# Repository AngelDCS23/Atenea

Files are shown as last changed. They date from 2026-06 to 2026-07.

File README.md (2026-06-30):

# Atenea — Cohete de 2 etapas con aviónica avanzada

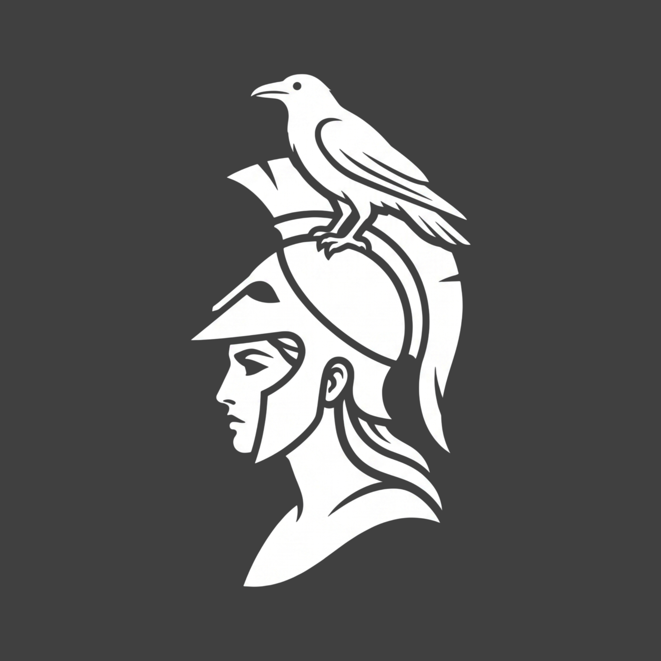
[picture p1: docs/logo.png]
Logo del proyecto


Atenea es un proyecto de cohete casero de dos etapas orientado al desarrollo de una aviónica robusta, modular y experimental. El objetivo es integrar sensores, control de vuelo, telemetría y seguimiento de antena para conseguir un sistema capaz de monitorizar y gestionar el vuelo de forma segura.

El proyecto está organizado en distintas áreas de trabajo:

- firmware: software embebido para la electrónica de vuelo y la estación terrestre.
- hardware: diseño y construcción de estructuras, electrónica y componentes mecánicos.
- ground_station: herramientas para recepción y procesamiento de datos.
- docs: documentación técnica y referencias del proyecto.

## Características principales

- Cohete de dos etapas con lógica de vuelo supervisada.
- Aviónica basada en ESP32-S3 para adquisición de datos y control.
- Integración de sensores como giroscopio, acelerómetro y barómetro.
- Máquina de estados para gestionar fases como despegue, separación, apogeo y recuperación.
- Telemetría por radio para seguimiento en tiempo real.
- Sistema de rastreo de antena para mejorar la recepción durante el vuelo.
- Enfoque modular para facilitar pruebas, desarrollo y futuras mejoras.

## Arquitectura general

El sistema se organiza en varios subsistemas clave:

1. Sensado y control
   - Lectura continua de sensores de actitud y presión.
   - Procesado en tiempo real para estimar el comportamiento del vehículo.
   - Implementación de estrategias de estabilidad activa.

2. Máquina de estados de vuelo
   - Gestión de eventos críticos del vuelo.
   - Transiciones seguras entre distintas fases.
   - Supervisión para prevenir acciones no deseadas.

3. Telemetría y comunicación
   - Transmisión de datos desde el cohete hacia la estación en tierra.
   - Uso de módulos de radio de bajo coste y alta simplicidad para enlaces de corto y medio alcance.

4. Seguimiento de antena
   - Posicionamiento automático de una antena direccional para mantener la comunicación.
   - Integración con datos de localización del cohete.

## Estructura del repositorio

- [docs](docs): documentación técnica general del proyecto.
- [firmware](firmware): código fuente para la aviónica del cohete y la estación.
- [ground_station](ground_station): aplicaciones o scripts para la estación terrestre.
- [hardware](hardware): diseños, modelos 3D y esquemas.

## Documentación relacionada

La documentación técnica más completa se encuentra en [docs/Proyecto_Cohete_Avionica.md](docs/Proyecto_Cohete_Avionica.md).

## Estado del desarrollo

El proyecto se encuentra en una fase inicial de desarrollo, centrada en la definición de la arquitectura, la selección de sensores y la implementación de los primeros módulos de firmware y hardware.

## Próximos pasos

- Definir y validar la lógica de la máquina de estados.
- Implementar la lectura y fusión de sensores para estimación de actitud.
- Integrar telemetría con la estación terrestre.
- Probar los subsistemas de control y recuperación.
- Continuar el desarrollo del hardware y la estructura del cohete.

## Licencia

Este proyecto se encuentra en desarrollo y su uso está orientado a fines educativos y experimentales.

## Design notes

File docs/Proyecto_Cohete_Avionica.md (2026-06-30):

# Proyecto Cohete Casero de 2 Etapas con Aviónica Avanzada (ESP32-S3)

Este documento recopila la estructura técnica, desafíos, soluciones y presupuesto estimado para el desarrollo de un cohete casero de dos etapas controlado por un **ESP32-S3 Sense**, incluyendo sistemas de estabilidad activa, telemetría y un rastreador de antena automatizado (*Antenna Tracker*).

---

## 1. Arquitectura del Sistema de Aviónica

Para ejecutar cálculos en tiempo real (como la estimación de actitud mediante fusión de sensores), el código del ESP32-S3 se estructurará en dos tareas principales aprovechando sus dos núcleos a 240 MHz:

* **Núcleo 0 (Control de Vuelo y Telemetría):** Lectura de la IMU (giroscopio/acelerómetro) y barómetro a alta frecuencia (100Hz - 200Hz), ejecución del algoritmo PID para los alerones activos y almacenamiento de datos en la tarjeta SD.
* **Núcleo 1 (Máquina de Estados de Vuelo y Cámara):** Gestión de la seguridad, detección de eventos de la Máquina de Estados (despegue, separación, apogeo), activación de servomotores de eyección y captura de imágenes/video.

### Máquina de Estados de Vuelo (FSM)
El software debe actuar como una máquina de estados finitos ultra-robusta sin el uso de funciones bloqueantes (`delay()`):
1.  **REPOSO (Pre-lanzamiento):** Calibración de sensores y espera de umbral de aceleración.
2.  **QUEMADO ETAPA 1:** Detección de aceleración positiva continua (> 2g).
3.  **SEPARACIÓN:** Caída drástica de la aceleración axial que indica el fin del empuje de la primera etapa.
4.  **ENCENDIDO ETAPA 2 (Condicionado):** *Regla de Oro de Seguridad:* Solo se activa si el ángulo de inclinación respecto a la vertical es inferior a 15°. Si es mayor, se aborta el encendido.
5.  **APOGEO:** Detección de velocidad vertical igual a cero y tendencia de presión barométrica negativa. Activación del paracaídas.
6.  **RECUPERACIÓN:** Transmisión de coordenadas GPS de alta prioridad hasta el aterrizaje.

---

## 2. Subsistemas Clave y Soluciones Técnicas

### Estabilidad Activa mediante Alerones (Opción Seleccionada)
* **Mecanismo:** 4 aletas aerodinámicas en la parte superior (*canards*) movidas por servomotores para corregir desviaciones en pleno vuelo.
* **Hardware:** Servos digitales **MG90S** con piñonería metálica, alimentados a 6V o 7.4V para maximizar la velocidad de respuesta (~0.08s por 60°). Al requerir deflexiones pequeñas (±5° a ±10°), el tiempo de reacción físico se reduce a unos ~6 milisegundos.
* **Software:** Algoritmo PID nativo utilizando el periférico MCPWM del ESP32 configurado a 200Hz o más, evitando ruidos de la IMU mediante filtros paso bajo (Low-Pass Filter).

### Propulsión y Combustible
* Se descartan los motores comerciales costosos y la cocción inestable de azúcar al fuego en interiores (riesgo crítico de CATO/explosión y autoignición).
* **Solución económica:** Uso de **Cohetes de Agua** (liberación mecánica mediante servos, coste 0€ por lanzamiento) o **Azúcar prensado en seco** (sin cocinar, requiriendo pruebas estáticas previas en un banco de tierra sin la electrónica a bordo).

### Telemetría y Enlace de Radio
* Se descarta el uso de tecnologías móviles (5G/4G) por el elevado coste de los módulos (100€-250€), las zonas muertas en altitud y el Efecto Doppler a alta velocidad.
* **Solución:** Módulos de radiofrecuencia de bajo coste como **LoRa (SX1278 a 868/915 MHz)** o transceptores **HC-12 (433 MHz)** conectados vía UART, permitiendo un alcance de entre 800m y 3km con antenas de látigo flexibles orientadas hacia abajo.

### Rastreador de Antena Automático (*Antenna Tracker*)
* **Funcionamiento:** Una estructura móvil *Pan-Tilt* en tierra equipada con una antena direccional de alta ganancia (tipo Yagi casera) que apunta automáticamente hacia el cohete.
* **Lógica:** El cohete envía sus coordenadas GPS (módulo **NEO-6M**). Un script de Python en el portátil (o un microcontrolador secundario en tierra) realiza el cálculo de trigonometría esférica (Azimut y Elevación) comparándolo con la posición de la estación base y mueve dos servos de alta potencia (**MG996R**).

---

## 3. Desglose del Presupuesto Estimado

A continuación se detalla la tabla de precios calculada para el enfoque de desarrollo "Low-Cost", asumiendo que ya se dispone del portátil y del procesador principal (**ESP32-S3 Sense**).

| Componente / Subsistema | Descripción / Función técnica | Cantidad | Precio Unitario (€) | Precio Total Estimado (€) |
| :--- | :--- | :---: | :---: | :---: |
| **Módulo GPS NEO-6M** | Localización del cohete y guiado del rastreador | 1 | 5,00 € | 5,00 € |
| **Transmisores de Radio** | Enlace inalámbrico (Módulos LoRa o HC-12) para cohete y tierra | 2 | 5,00 € | 10,00 € |
| **Servos Digitales MG90S** | Servomotores rápidos con piñones de metal para los alerones activos | 2 | 4,00 € | 8,00 € |
| **Micro Servo SG90** | Servomotor básico para el pestillo de eyección del paracaídas | 1 | 2,00 € | 2,00 € |
| **Batería LiPo 2S (7.4V)** | Alimentación dedicada para servos y aviónica del cohete (ej. 450mAh) | 1 | 7,00 € | 7,00 € |
| **Adaptador USB a TTL** | Chip CP2102 para conectar el receptor de radio de tierra al portátil | 1 | 2,00 € | 2,00 € |
| **Microcontrolador Tierra** | Placa Arduino Nano (clon) para controlar los servos del rastreador | 1 | 3,00 € | 3,00 € |
| **Servos de Potencia MG996R** | Servomotores de alto torque para el movimiento Pan-Tilt de la antena | 2 | 5,00 € | 10,00 € |
| **Antena Yagi Casera** | Fabricación propia con varillas de metal/perchas y conectores | 1 | 2,00 € | 2,00 € |
| **Fuselaje y Estructura** | Tubos de cartón/PVC, botellas PET, tornillería y filamento 3D | - | 10,00 € | 10,00 € |
| **Material Paracaídas** | Tela ligera de paraguas viejo o bolsa resistente e hilo de pescar | 1 | 2,00 € | 2,00 € |
| **TOTAL ESTIMADO** | **Coste de hardware para el sistema aeroespacial completo** | - | - | **61,00 €** |

*Nota sobre la propulsión:* Si se opta por cohetes de agua, el coste operativo es de 0,00€. En caso de utilizar propulsor de azúcar (KNO3 + Azúcar glass), los ingredientes químicos añaden aproximadamente **10,00 €** adicionales para múltiples lotes de prueba.

---

## 4. Próximos Pasos con el Giroscopio de 6 Ejes

Dado que vas a comenzar por el sistema de medición de actitud, ten en cuenta estas tres pautas clave para tu IMU de 6 ejes:

1.  **Configuración de Rango Máximo:** Configura el giroscopio a su escala completa (típicamente **±2000 °/s**) y el acelerómetro a **±16g**. Los valores por defecto de desarrollo (como ±2g) se saturarán instantáneamente con la vibración y aceleración del despegue.
2.  **Amortiguación Mecánica:** No atornilles ni pegues la IMU directamente a la estructura rígida del cohete. El ruido de alta frecuencia del motor falseará las lecturas. Usa espuma de alta densidad o gel de silicona entre el chasis y la PCB.
3.  **Algoritmo de Fusión:** Implementa un filtro complementario (ligero y rápido) o un filtro de Kalman optimizado en el Núcleo 0 para combinar las lecturas del giroscopio (preciso a corto plazo) con el acelerómetro (estable a largo plazo) y obtener el ángulo real de inclinación en tiempo real.

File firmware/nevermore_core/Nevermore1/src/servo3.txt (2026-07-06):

#include <Arduino.h>
#include "I2Cdev.h"
#include "MPU6050.h"
#include "Wire.h"
#include <ESP32Servo.h> 

MPU6050 sensor;

Servo servoPitch1;
Servo servoPitch2;
const int PIN_SERVO_PITCH1 = 1;
const int PIN_SERVO_PITCH2 = 2; 

Servo servoRoll;
const int PIN_SERVO_ROLL = 3; 

int16_t ax, ay, az;
int16_t gx, gy, gz;

float pitch = 0.0;
float roll = 0.0;
unsigned long tiempoAnterior;

const float SETPOINT = 0.0; 
const int CENTRO_SERVO = 90;

float Kp = 1.0;  
float Ki = 0.0;  
float Kd = 0.05; 

float errorPrevioPitch = 0.0;
float errorIntegralPitch = 0.0;

float errorPrevioRoll = 0.0;
float errorIntegralRoll = 0.0;

void setup() {
  Serial.begin(115200);
  Wire.begin(5, 6); 
  
  sensor.initialize();

  sensor.setFullScaleGyroRange(MPU6050_GYRO_FS_2000);
  sensor.setFullScaleAccelRange(MPU6050_ACCEL_FS_8);

  if (sensor.testConnection()) {
      Serial.println("Sensor MPU6050 iniciado correctamente con GPIO 5 y 6");
  } else {
      Serial.println("Error al iniciar el sensor MPU6050");
  }

  servoPitch1.attach(PIN_SERVO_PITCH1, 500, 2500); 
  servoPitch2.attach(PIN_SERVO_PITCH2, 500, 2500); 
  servoPitch1.write(CENTRO_SERVO);
  servoPitch2.write(CENTRO_SERVO);

  servoRoll.attach(PIN_SERVO_ROLL, 500, 2500);
  servoRoll.write(CENTRO_SERVO);

  tiempoAnterior = micros();
}

void loop() {
  // 1. LEER SENSOR
  sensor.getAcceleration(&ax, &ay, &az);
  sensor.getRotation(&gx, &gy, &gz);

  unsigned long tiempoActual = micros();
  float dt = (tiempoActual - tiempoAnterior) / 1000000.0;
  tiempoAnterior = tiempoActual;

  float accelRoll = atan2(ay, az) * 180.0 / M_PI;
  float accelPitch = atan2(-ax, sqrt((float)ay * (float)ay + (float)az * (float)az)) * 180.0 / M_PI;

  float gyroX_dps = gx / 16.4;
  float gyroY_dps = gy / 16.4;

  roll = 0.95 * (roll + gyroX_dps * dt) + 0.05 * accelRoll;
  pitch = 0.95 * (pitch + gyroY_dps * dt) + 0.05 * accelPitch;

  float errorPitch = SETPOINT - pitch;
  
  errorIntegralPitch += (errorPitch * dt);
  errorIntegralPitch = constrain(errorIntegralPitch, -20.0, 20.0); 

  float derivativoPitch = (errorPitch - errorPrevioPitch) / dt;
  float salidaPID_Pitch = (Kp * errorPitch) + (Ki * errorIntegralPitch) + (Kd * derivativoPitch);
  errorPrevioPitch = errorPitch;

  if (abs(salidaPID_Pitch) < 1.0) salidaPID_Pitch = 0.0;

  int anguloPitch = CENTRO_SERVO - salidaPID_Pitch;
  anguloPitch = constrain(anguloPitch, 60, 120);

  servoPitch1.write(anguloPitch);
  servoPitch2.write(anguloPitch); 

  float errorRoll = SETPOINT - roll;
  
  errorIntegralRoll += (errorRoll * dt);
  errorIntegralRoll = constrain(errorIntegralRoll, -20.0, 20.0);

  float derivativoRoll = (errorRoll - errorPrevioRoll) / dt;
  float salidaPID_Roll = (Kp * errorRoll) + (Ki * errorIntegralRoll) + (Kd * derivativoRoll);
  errorPrevioRoll = errorRoll;

  if (abs(salidaPID_Roll) < 1.0) salidaPID_Roll = 0.0;

  int anguloRoll = CENTRO_SERVO + salidaPID_Roll; 
  anguloRoll = constrain(anguloRoll, 60, 120);

  servoRoll.write(anguloRoll);

  Serial.print("Pitch:"); Serial.print(pitch); Serial.print(",");
  Serial.print("Roll:");  Serial.print(roll);  Serial.print(",");
  Serial.print("Angulo_Pitch:"); Serial.print(anguloPitch); Serial.print(",");
  Serial.print("Angulo_Roll:");  Serial.println(anguloRoll);

  delay(10); 
}

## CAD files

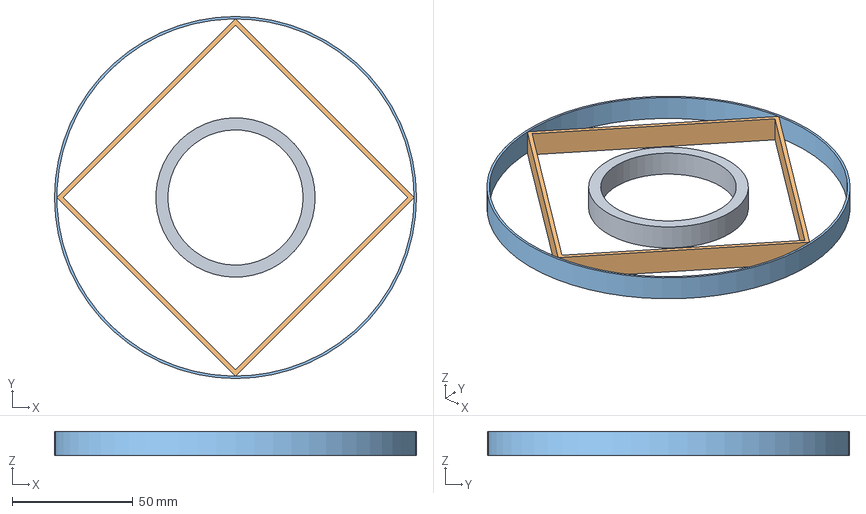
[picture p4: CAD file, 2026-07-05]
hardware/prototipo1.FCStd
150.0 x 150.0 x 10.0 mm

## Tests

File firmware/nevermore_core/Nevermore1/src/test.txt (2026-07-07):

#include <Arduino.h>
#include <ESP32Servo.h>

Servo miServoMetal;
Servo miServoMetal2;
Servo miServoPlastic;

// Usamos el pin físico D1 (que equivale al GPIO2), 
// ya que comprobaste que funciona perfectamente.
const int PIN_SERVOP = 1;
const int PIN_SERVO = 2; 
const int PIN_SERVO2 = 3;

void setup() {
  Serial.begin(115200);
  
  // Espera activa para que no te pierdas los textos por el USB
  while (!Serial) {
    delay(10);
  }
  
  Serial.println("--- TEST DE FUERZA PARA SERVO MG90S ---");
  
  // Configuramos el servo con los anchos de pulso estándar
  miServoPlastic.attach(PIN_SERVOP, 500, 2500);
  miServoMetal.attach(PIN_SERVO, 500, 2500);
  miServoMetal2.attach(PIN_SERVO2, 500, 2500);
}

void loop() {
  Serial.println("Posicion: 0 grados");
  miServoPlastic.write(0);
  miServoMetal.write(0);
  miServoMetal2.write(0);
  delay(1500); // Tiempo suficiente para que el motor llegue y exija corriente

  Serial.println("Posicion: 90 grados (Centro)");
  miServoPlastic.write(90);
  miServoMetal.write(90);
  miServoMetal2.write(90);
  delay(1500);

  Serial.println("Posicion: 180 grados");
  miServoPlastic.write(180);
  miServoMetal.write(180);
  miServoMetal2.write(180);
  delay(1500);
  
  Serial.println("Volviendo a: 90 grados (Centro)");
  miServoPlastic.write(90);
  miServoMetal.write(90);
  miServoMetal2.write(90);
  delay(1500);
  
  Serial.println("---------------------------------------");
}

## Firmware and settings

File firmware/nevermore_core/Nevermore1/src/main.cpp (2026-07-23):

#include <Arduino.h>
#include "I2Cdev.h"
#include "MPU6050.h"
#include "Wire.h"
#include <ESP32Servo.h> 
#include <TinyGPSPlus.h>

#define GPS_RX_PIN 44
#define GPS_TX_PIN 43

MPU6050 sensor;
TinyGPSPlus gps;

unsigned long ultimoAviso = 0;

// --- CONFIGURACIÓN DE LOS SERVOS ---
Servo servo_EjeX;     // El que se moverá con la inclinación X
Servo servo_EjeY_1;   // El que se moverá con la inclinación Y (Motor 1)
Servo servo_EjeY_2;   // El que se moverá con la inclinación Y (Motor 2)

const int PIN_SERVO_X = D0; 
const int PIN_SERVO_Y1 = D1;
const int PIN_SERVO_Y2 = D2;

int16_t ax, ay, az;
int16_t gx, gy, gz;

float pitch = 0.0; // Lo usaremos como Eje X
float roll = 0.0;  // Lo usaremos como Eje Y

unsigned long tiempoAnterior;

const float SETPOINT_X = 0.0; 
const float SETPOINT_Y = 0.0;
const int CENTRO_SERVO = 90;

// Constantes PID Eje X
float KpX = 1.0;
float KiX = 0.0;
float KdX = 0.05;

// Constantes PID Eje Y
float KpY = 0.8;
float KiY = 0.0;
float KdY = 0.05;

// Memoria del PID
float errorPrevioX = 0.0;
float errorIntegralX = 0.0;
float errorPrevioY = 0.0;
float errorIntegralY = 0.0;

void setup() {
  Serial.begin(115200);
  Wire.begin();
  sensor.initialize();

  Serial1.begin(9600, SERIAL_8N1, GPS_RX_PIN, GPS_TX_PIN);
  sensor.setFullScaleGyroRange(MPU6050_GYRO_FS_2000);
  sensor.setFullScaleAccelRange(MPU6050_ACCEL_FS_8);

  if (sensor.testConnection()) {
      Serial.println("Sensor iniciado correctamente");
  } else {
      Serial.println("Error al iniciar el sensor");
  }

  // 1. Asignar temporizadores independientes
  ESP32PWM::allocateTimer(0);
  ESP32PWM::allocateTimer(1);
  ESP32PWM::allocateTimer(2);
  ESP32PWM::allocateTimer(3);

  // 2. Definir la frecuencia
  servo_EjeX.setPeriodHertz(50);
  servo_EjeY_1.setPeriodHertz(50);
  servo_EjeY_2.setPeriodHertz(50);

  // 3. Conectar a los pines
  servo_EjeX.attach(PIN_SERVO_X, 500, 2500);
  servo_EjeY_1.attach(PIN_SERVO_Y1, 500, 2500);
  servo_EjeY_2.attach(PIN_SERVO_Y2, 500, 2500);
  
  // 4. Centrar los motores
  servo_EjeX.write(CENTRO_SERVO);
  servo_EjeY_1.write(CENTRO_SERVO);
  servo_EjeY_2.write(CENTRO_SERVO);

  tiempoAnterior = micros();
}

void loop() {

  while (Serial1.available() > 0) {
    gps.encode(Serial1.read());
  }

  if (gps.location.isUpdated()) {
    Serial.print("Latitud: "); 
    Serial.print(gps.location.lat(), 6);
    Serial.print(" | Longitud: "); 
    Serial.print(gps.location.lng(), 6);
    Serial.print(" | Altitud: "); 
    Serial.print(gps.altitude.meters());
    Serial.print(" m | Satélites conectados: "); 
    Serial.println(gps.satellites.value());
  }

  if (millis() - ultimoAviso > 5000 && gps.satellites.value() == 0) {
    Serial.println("Buscando satélites...");
    ultimoAviso = millis();
  }

  sensor.getAcceleration(&ax, &ay, &az);
  sensor.getRotation(&gx, &gy, &gz);

  unsigned long tiempoActual = micros();
  float dt = (tiempoActual - tiempoAnterior) / 1000000.0;
  tiempoAnterior = tiempoActual;

  // Cálculo de inclinación (X e Y)
  float accelRoll = atan2(ay, az) * 180.0 / M_PI;
  float accelPitch = atan2(-ax, sqrt((float)ay * (float)ay + (float)az * (float)az)) * 180.0 / M_PI;

  float gyroX_dps = gx / 16.4;
  float gyroY_dps = gy / 16.4;

  // Pitch representará nuestro EJE X
  pitch = 0.95 * (pitch + gyroY_dps * dt) + 0.05 * accelPitch;
  // Roll representará nuestro EJE Y
  roll = 0.95 * (roll + gyroX_dps * dt) + 0.05 * accelRoll;


  // --- CÁLCULO PID EJE X (Solo afecta al D0) ---
  float errorActualX = SETPOINT_X - pitch;
  float proporcionalX = KpX * errorActualX;
  
  errorIntegralX = errorIntegralX + (errorActualX * dt);
  errorIntegralX = constrain(errorIntegralX, -20.0, 20.0);

  float integralX = KiX * errorIntegralX;
  float derivativoX = KdX * ((errorActualX - errorPrevioX) / dt);
  float salidaPID_X = proporcionalX + integralX + derivativoX;

  errorPrevioX = errorActualX;

  // --- CÁLCULO PID EJE Y (Afecta a D1 y D2) ---
  float errorActualY = SETPOINT_Y - roll;
  float proporcionalY = KpY * errorActualY;

  errorIntegralY = errorIntegralY + (errorActualY * dt);
  errorIntegralY = constrain(errorIntegralY, -20.0, 20.0);

  float integralY = KiY * errorIntegralY;
  float derivativoY = KdY * ((errorActualY - errorPrevioY) / dt);
  float salidaPID_Y = proporcionalY + integralY + derivativoY;

  errorPrevioY = errorActualY;

  // --- BANDA MUERTA ---
  if (abs(salidaPID_X) < 1.0) salidaPID_X = 0.0;
  if (abs(salidaPID_Y) < 1.0) salidaPID_Y = 0.0;

  // 1. El motor del pin D0 se mueve SOLO con el Eje X
  int anguloEjeX = CENTRO_SERVO - salidaPID_X;
  anguloEjeX = constrain(anguloEjeX, 60, 120); 
  servo_EjeX.write(anguloEjeX);

  // 2. Los motores de los pines D1 y D2 se mueven SOLO con el Eje Y
  int anguloEjeY = CENTRO_SERVO + salidaPID_Y; 
  anguloEjeY = constrain(anguloEjeY, 60, 120); 
  
  servo_EjeY_1.write(anguloEjeY);
  servo_EjeY_2.write(anguloEjeY); 

  Serial.print("Inclinacion_X:");
  Serial.print(pitch);
  Serial.print(" | Inclinacion_Y:");
  Serial.print(roll);
  Serial.print(" | Servo_D0:");
  Serial.print(anguloEjeX);
  Serial.print(" | Servos_D1_D2:");
  Serial.println(anguloEjeY); 
}

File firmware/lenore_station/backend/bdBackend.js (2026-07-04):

const { SerialPort } = require('serialport');
const { ReadlineParser } = require('@serialport/parser-readline');
const sqlite3 = require('sqlite3').verbose();
const WebSocket = require('ws');

const PUERTO_SERIAL = '/dev/ttyACM0'
const BAUDIOS = 57600;
const DB_FILE = 'atenea_flight_data.db';

let datos_actuales = {
    pitch: 0.0,
    roll: 0.0,
    altitud: 0.0,
    velocidad: 0.0,
    servo_pitch: 90
};

const db = new sqlite3.Database(DB_FILE, (err) => {
    if (err) console.error('[-] Error al abrir base de datos', err.message);
    else console.log('[DB] Base de datos SQLite iniciada correctamente.');
});

db.serialize(() => {
    db.run('PRAGMA journal_mode = WAL;');
    db.run('PRAGMA synchronous = NORMAL;');
    
    db.run(`CREATE TABLE IF NOT EXISTS telemetria (
        id INTEGER PRIMARY KEY AUTOINCREMENT,
        timestamp DATETIME DEFAULT CURRENT_TIMESTAMP,
        pitch REAL,
        roll REAL,
        altitud REAL,
        velocidad REAL
    )`);
});

let loteGuardado = [];
const TAMANO_LOTE = 10;

function guardarEnBaseDeDatos() {
    if (loteGuardado.length === 0) return;
    
    const datosProcesar = [...loteGuardado];
    loteGuardado = [];

    db.serialize(() => {
        db.run("BEGIN TRANSACTION");
        const stmt = db.prepare("INSERT INTO telemetria (pitch, roll, altitud, velocidad) VALUES (?, ?, ?, ?)");
        for (let dato of datosProcesar) {
            stmt.run(dato.pitch, dato.roll, dato.altitud, dato.velocidad);
        }
        stmt.finalize();
        db.run("COMMIT");
    });
}

const wss = new WebSocket.Server({ port: 8765 }, () => {
    console.log('[WEB] Servidor de telemetría online en ws://localhost:8765');
});

wss.on('connection', (ws) => {
    console.log('[WEB] ¡Nuevo Dashboard conectado!');
});

setInterval(() => {
    const jsonDatos = JSON.stringify(datos_actuales);
    wss.clients.forEach((cliente) => {
        if (cliente.readyState === WebSocket.OPEN) {
            cliente.send(jsonDatos);
        }
    });
}, 50);

console.log(`[USB] Intentando conectar a ${PUERTO_SERIAL} a ${BAUDIOS} baudios...`);

const puerto = new SerialPort({ path: PUERTO_SERIAL, baudRate: BAUDIOS }, (err) => {
    if (err) {
        console.error(`[USB ERROR] No se pudo abrir el puerto: ${err.message}`);
        console.log('Asegúrate de cerrar VS Code / Arduino IDE y de tener permisos dialout.');
    }
});

const parser = puerto.pipe(new ReadlineParser({ delimiter: '\n' }));

puerto.on('open', () => {
    console.log('[USB] ¡Conectado al cohete Atenea! Escuchando datos...');
});

parser.on('data', (linea) => {
    const valores = linea.trim().split(',');
    
    if (valores.length >= 2) {
        const pitch = parseFloat(valores[0]);
        const roll = parseFloat(valores[1]);
        const altitud = valores.length > 2 ? parseFloat(valores[2]) : 0.0;
        const velocidad = valores.length > 3 ? parseFloat(valores[3]) : 0.0;
        const servo_pitch = valores.length > 4 ? parseInt(valores[4], 10) : 90;

        if (!isNaN(pitch) && !isNaN(roll)) {
            datos_actuales = { pitch, roll, altitud, velocidad, servo_pitch };

            loteGuardado.push(datos_actuales);
            if (loteGuardado.length >= TAMANO_LOTE) {
                guardarEnBaseDeDatos();
            }
        }
    }
});

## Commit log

2026-06-30 Add Atenea Flight Computer dashboard and initial project structure - Created a new HTML dashboard for the Atenea Flight Computer with instruments for speed, altitude, and artificial horizon. - Implem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
2026-07-02 Add ESP32Servo library and implement servo control in main application; include pinout diagrams
2026-07-02 Add initial schematic and symbol library for Nevermore-1 project - Created the main schematic file for the Nevermore-1 project, including components such as the Seeed Studio XIAO ESP32-S3 and MPU-605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
    [Nevermore-1.kicad_pcb, Nevermore-1.kicad_sch]
2026-07-02 Enhance sensor configuration and calculations in main application; update gyro and accel ranges, improve pitch and roll calculations
    [Nevermore-1.kicad_sch]
2026-07-06 Update platformio.ini and main.cpp for improved servo control; add GPS functionality and new servo configurations
2026-07-06 Remove lock files for Nevermore-1 schematics to clean up project directory
    [Nevermore-1.kicad_sch]
2026-07-07 Refactor servo configuration and control logic; add new servo support and improve PID calculations
